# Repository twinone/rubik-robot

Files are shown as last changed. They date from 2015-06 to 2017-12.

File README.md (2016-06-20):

# rubik-robot

A low cost, 3D printable Rubik's Cube solving robot. This project was built in about two or three weeks, incuding the hardware design, software, etc. Just printing and assembling it should take about two days, so you can do it in a weekend. The total cost of the project is about 45$, from which 35$ are for the non-printable hardware, and 10$ are the actual printed parts.

Timelapse of the robot in action

## Hardware used

* 3D Printer (BQ Prusa i3 Hephestos)
* An Android phone (OnePlus One)
* 4x micro servo (TowerPro MG 995)
* 4x servo (Tower Pro SG 90)
* Arduino Nano, breadboard, jumper wires, etc.
* Bluetooth module (HC-05)
* M3 screws / nuts

## Parts

 - OpenSCAD designs for the printable parts (see `scad/`).
 - The sketch that runs on the Arduino (see `arduino/`).
 - An Android application (see `android/`) that uses the camera and works
   in cooperation with the Arduino to scan and solve the cube automatically.
 - Standalone utility apps (see `utils/`) for talking to the Arduino.

## Make your own

See [`BUILDING.md`](https://github.com/twinone/rubik-robot/blob/master/BUILDING.md)

## Authors

* [@twinone](https://github.com/twinone)
* [@jmendeth](https://github.com/jmendeth)

## License

Everything is MIT-licensed (see `LICENSE`) except this README and
the documentation files under `docs`, which are under a
[Creative Commons Attribution-NonCommercial 4.0 International License](https://creativecommons.org/licenses/by-nc/4.0).

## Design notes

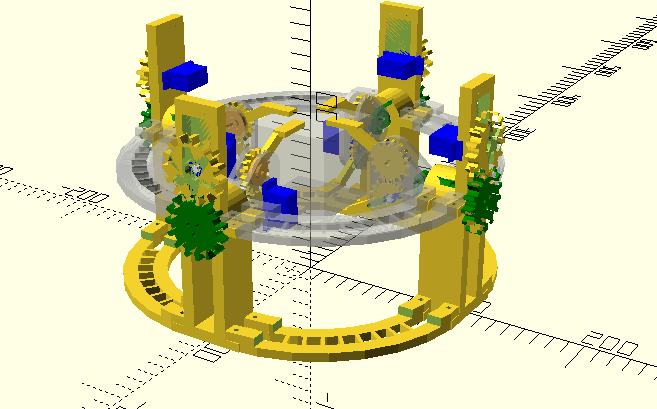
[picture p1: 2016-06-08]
docs/media/design.png

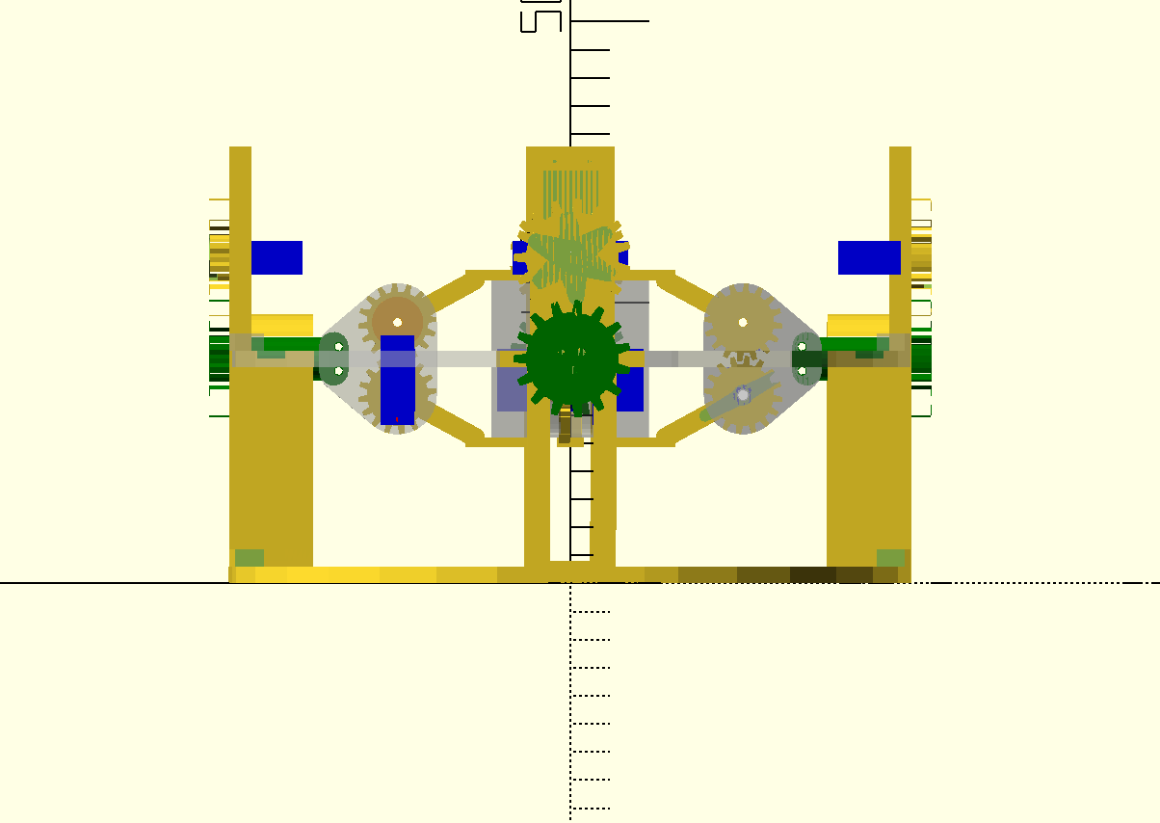
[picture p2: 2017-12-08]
docs/media/side.png

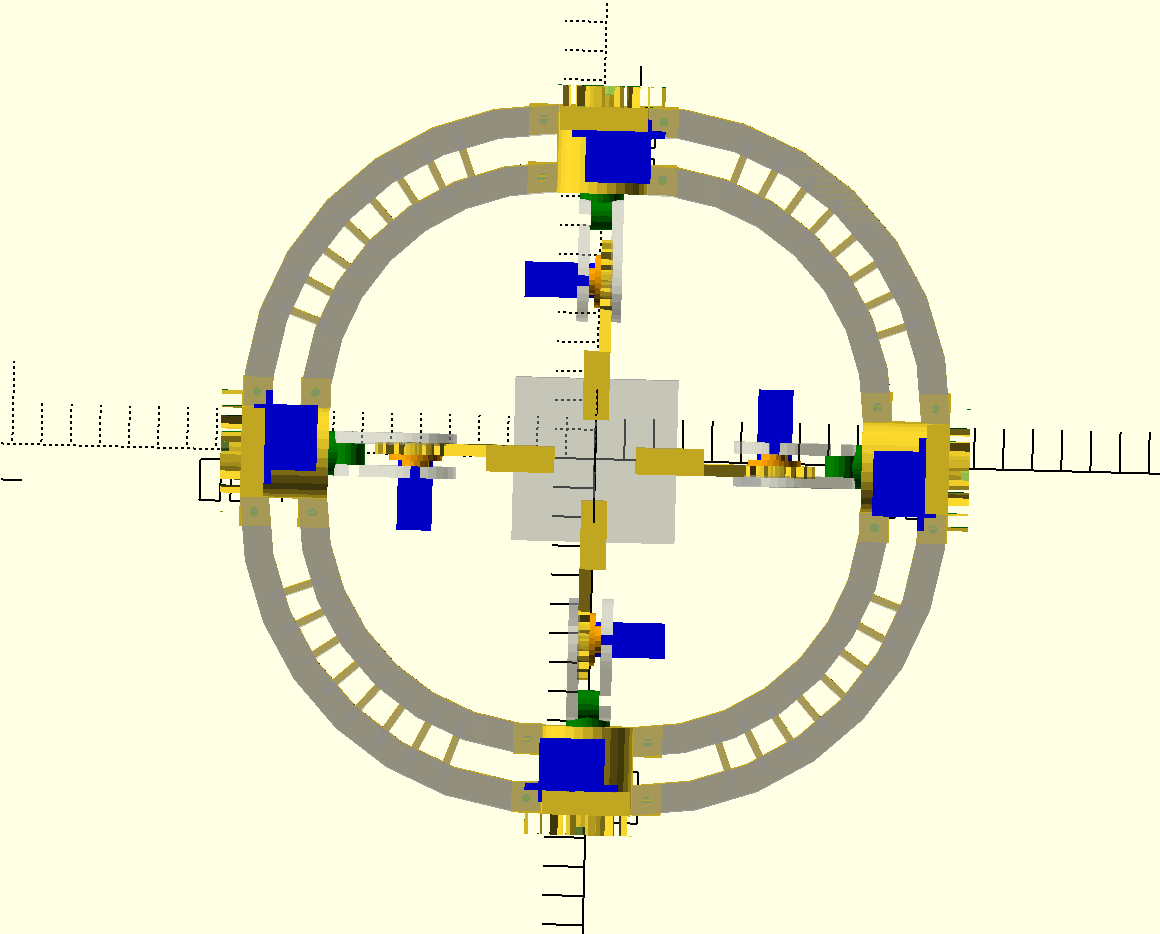
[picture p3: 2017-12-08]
docs/media/top.png

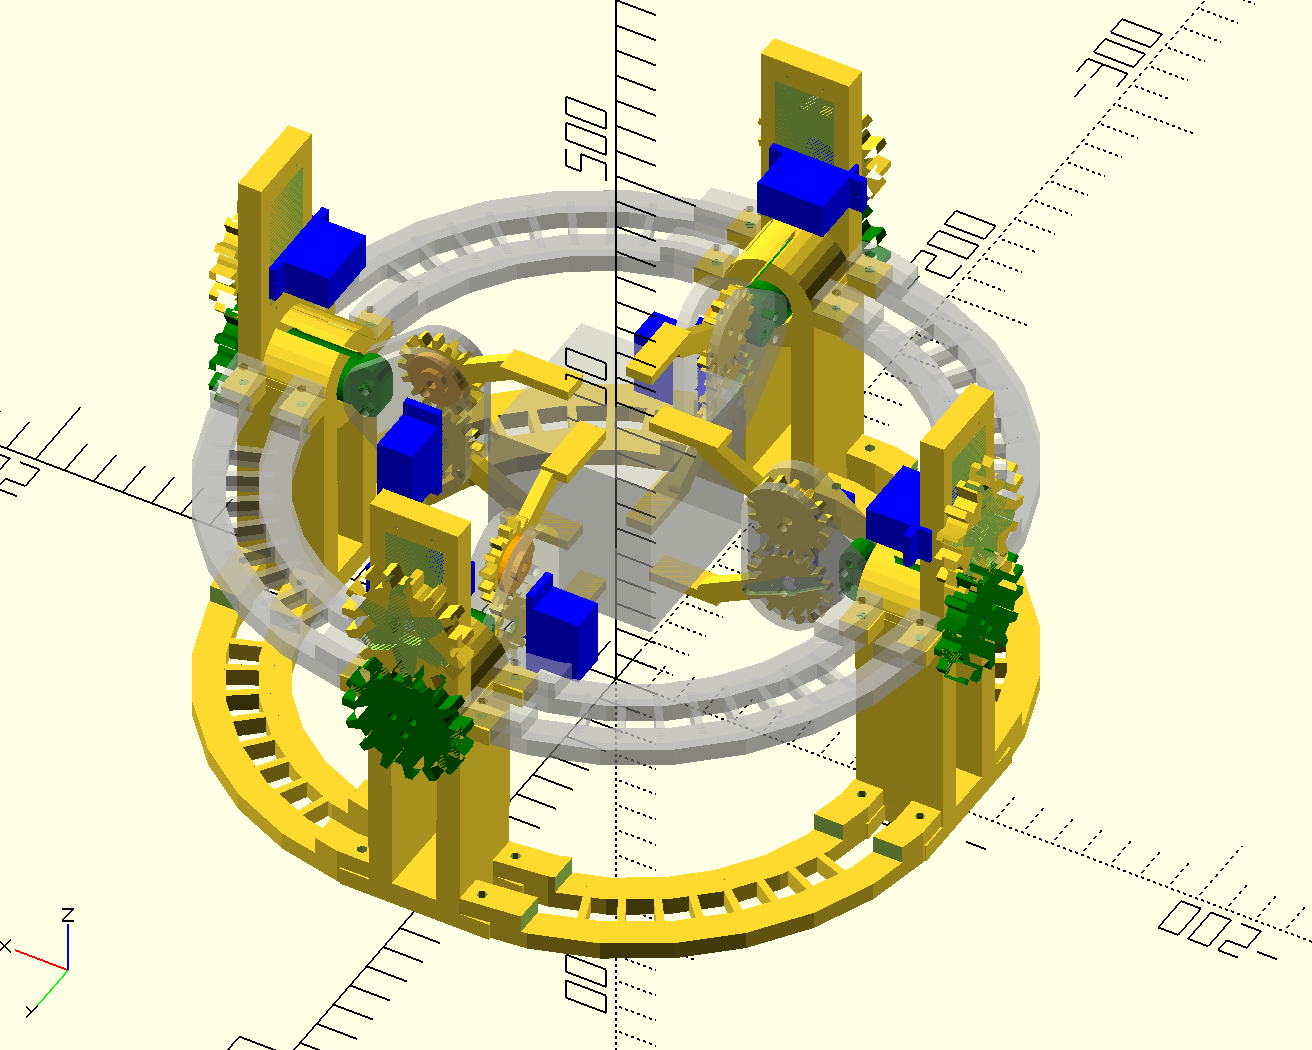
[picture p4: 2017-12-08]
docs/media/perspective.png

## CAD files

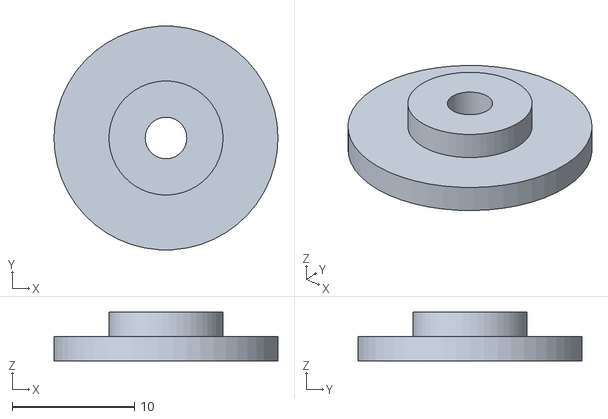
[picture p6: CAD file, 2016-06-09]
scad/build/grip_pad.stl
18.3 x 18.3 x 4.00

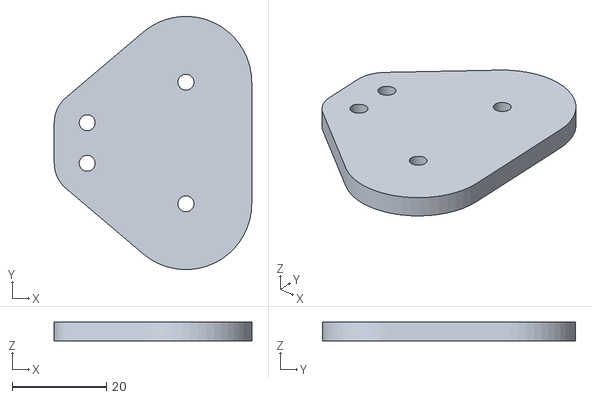
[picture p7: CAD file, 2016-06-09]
scad/build/grip_top.stl
42.0 x 53.8 x 4.00

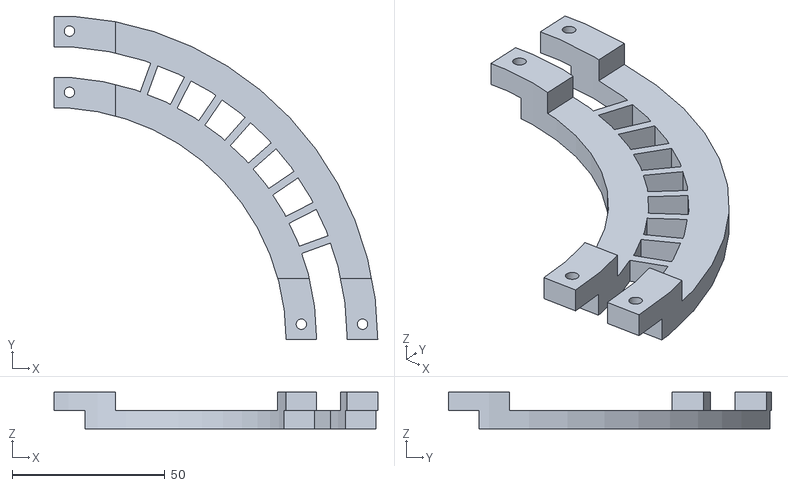
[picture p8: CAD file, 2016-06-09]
scad/build/foot.stl
105.8 x 105.6 x 12.0

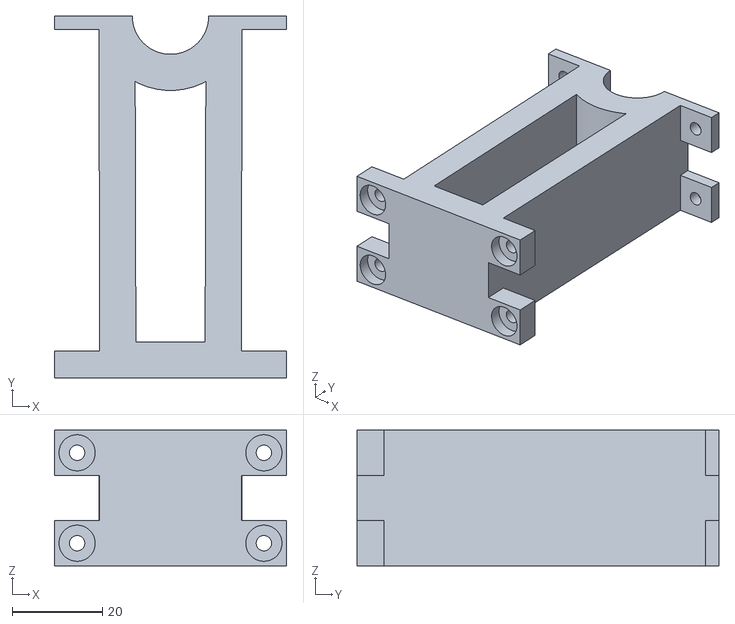
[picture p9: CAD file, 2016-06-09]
scad/build/holder_bottom.stl
51.3 x 80.0 x 30.0

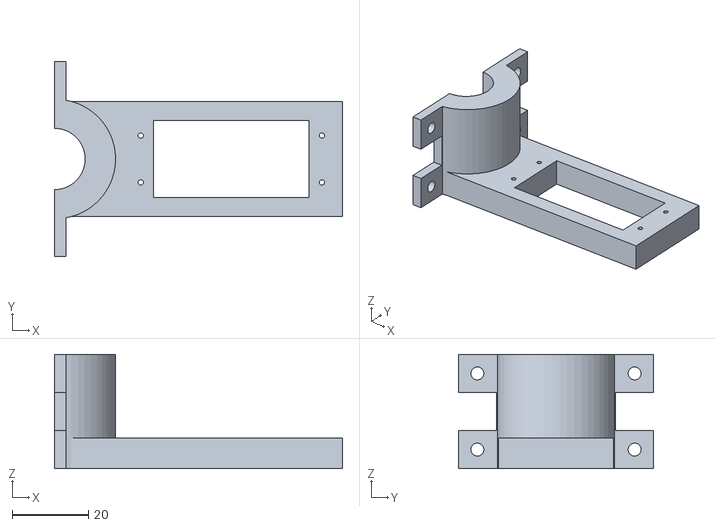
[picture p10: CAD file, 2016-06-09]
scad/build/holder_top.stl
75.7 x 51.3 x 30.0

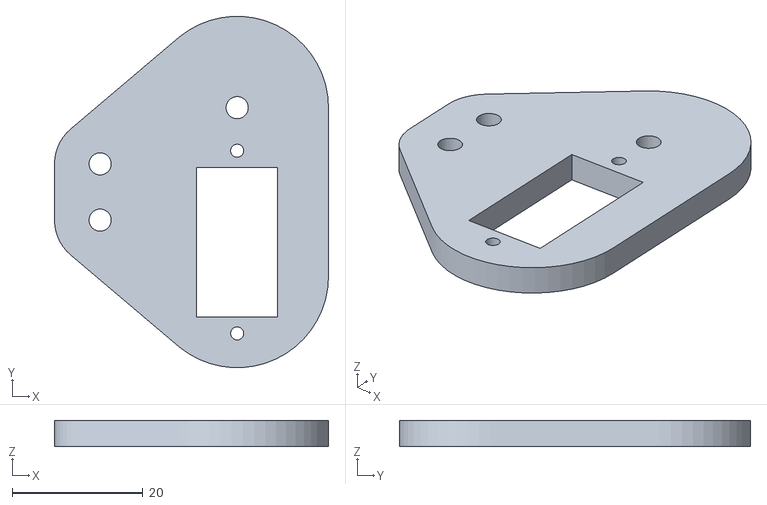
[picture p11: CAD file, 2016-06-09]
scad/build/grip_bottom.stl
42.0 x 53.8 x 4.00

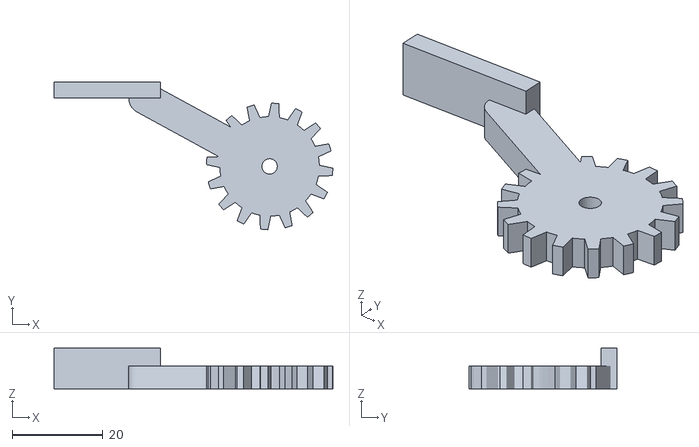
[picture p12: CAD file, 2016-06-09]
scad/build/arm_left.stl
61.6 x 32.6 x 9.00

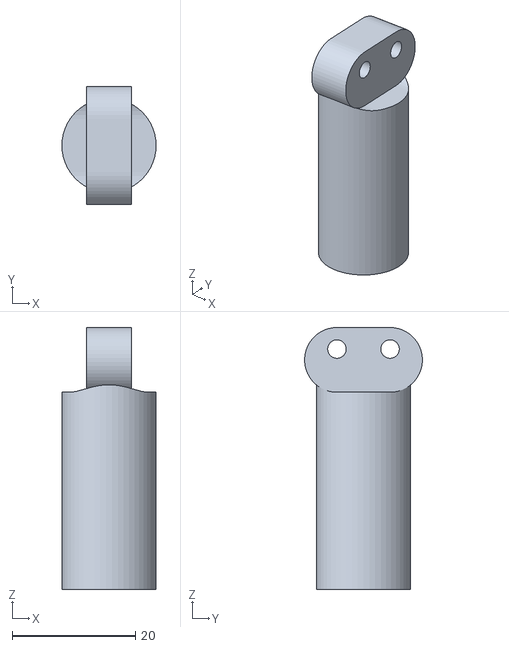
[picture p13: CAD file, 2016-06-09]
scad/build/grip_cylinder.stl
15.3 x 19.1 x 42.5

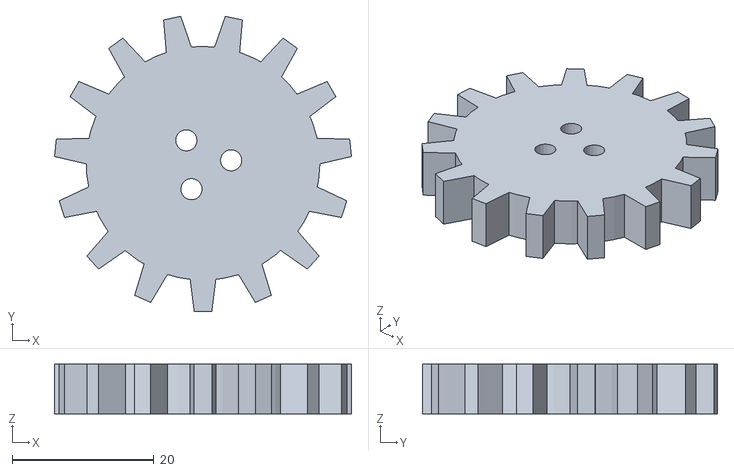
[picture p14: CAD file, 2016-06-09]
scad/build/grip_gear.stl
41.9 x 41.7 x 7.00

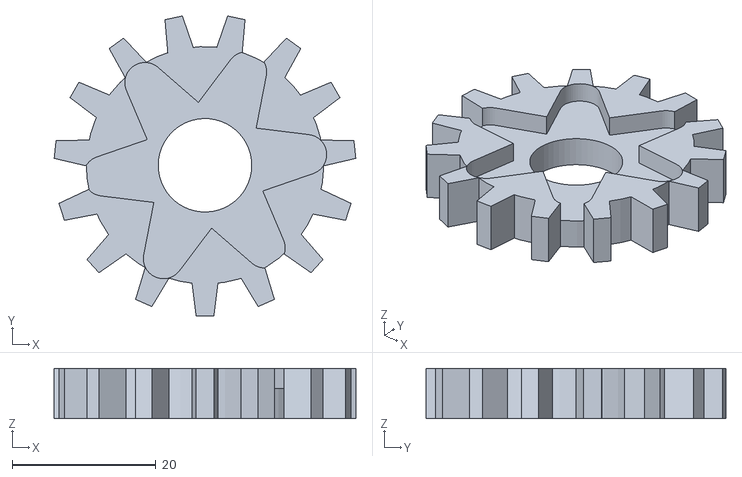
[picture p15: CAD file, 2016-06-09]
scad/build/servo_gear.stl
41.9 x 41.7 x 7.00

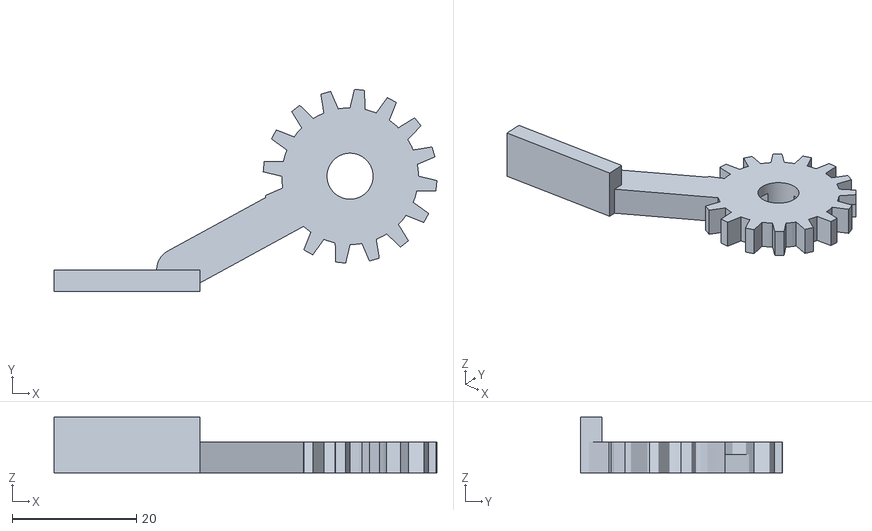
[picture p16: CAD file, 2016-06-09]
scad/build/arm_right.stl
61.6 x 32.6 x 9.00

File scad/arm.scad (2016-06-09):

use <buildvars.scad>
use <util/util.scad>
use <util/gear.scad>
use <util/mservo_enclosing.scad>

teeth = 16;
r = gear_r();


sideways_length = (56 - arm_c2c())/2;
// redefined here
function arm_length() = enclosing_dst_large() + 6;
l1 = arm_length();
l2 = sideways_length;
function arm_angle() = atan(l2/l1);
function arm_diagonal_length() = sqrt(l1*l1+l2*l2);

// length: center to center length
module arm(length, r=arm_width()/2, center = false, s1=true, s2=true) {
    move = center ? -length/2 : 0;
    translate([move,0,0])
    difference() {
        hull() {
            circle(r=r);
            translate([length,0,0])
            circle(r=r);
        }
        if(s1==true)
        screw_hole();
        if(s2==true)
        translate([length,0,0]) screw_hole();
    }
}
start_angle = 40;
angle = 360;

module sideways(height) {
    grip_h = 9;
    rotate(-90)
    translate([0,arm_length(),0]) {
        translate([0,0,height-grip_h])
        linear_extrude(height=grip_h)
        translate([sideways_length,-arm_width()/2,0]) square([arm_width()/2,20+arm_width()/2]);
    }
}

module arm_left(height) {
    mirror([0,1,0]) {
        gear(r=r, h=height, teeth=teeth, center_r = screw_r()+tolerance(), angle = angle, start_angle = start_angle);
        rotate(-arm_angle())
        linear_extrude(height=height) {
            arm(length=arm_diagonal_length(), r = arm_width()/2,s2=false);
        }
        sideways(height);
    }
}

module arm_right(height) {
    rotate(180-arm_angle())
    remove_servo_horn(horns=[true,false,true,false], h1=2)
    rotate(180+arm_angle())
    difference() {
        union() {
            rotate([0,0,-360/teeth/2]) // so they're aligned
            gear(r=r, h=height, teeth=teeth, center_r = screw_r()+tolerance(), angle = angle, start_angle = start_angle);
            rotate(-arm_angle())
            linear_extrude(height=height) {
                arm(length=arm_diagonal_length(), r = arm_width()/2,s2=false);
            }
            sideways(height);
        }
    }
}


module arms(height = arm_height(), center = true, angle = 0, extrasep = 0, left=true, right=true) {
    move = center ? -arm_c2c()/2 : 0;
    translate([0,move-extrasep,0]) {
        if(left)
        translate([0,arm_c2c()+extrasep*2,0])
        rotate([0,0,angle])
        arm_left(height);
        
        if(right)
        rotate([0,0,-angle])
        arm_right(height);
    }
}

arms();

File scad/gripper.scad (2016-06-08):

use <buildvars.scad>
use <arm.scad>

use <util/util.scad>
use <util/gear.scad>
use <util/mservo.scad>
use <util/mservo_enclosing.scad>


module dup(vec=[0,1,0]) {
    children();
    mirror(vec) children();
}


module base(servo_hole = true) {
    module main() {
        r = base_rounding_radius();
        module circles(r,a) {
            translate([0,arm_c2c()/2,0])
            circle(r=a?r:r*2);

            translate([back_y(),back_x()/2,0])
            circle(r=r);
        }
        linear_extrude(height=servo_base_height())
        difference() {
            hull() dup() circles(r,false);
            dup() circles(screw_r()+tolerance(),true, $fn=30);
            
        }
    }
    difference() {
        main();
        if (servo_hole) {
            translate([-servo_d()/2-tolerance(),-arm_c2c()/2+servo_w()-servo_r()+tolerance(),0]){
                rotate([0,0,-90]) {
                    cube([servo_w()+2*tolerance(),servo_d()+2*tolerance(),servo_base_height()]);
                }
            }
            translate([0,-arm_c2c()/2,0]){
                rotate([0,0,-90]) {
                    servo_screws();
                }
            }
        }
    }
}

module top() {
    base(false);
}

module show_servo() {
    translate([0,-arm_c2c()/2,0]){
        translate([0,0,-servo_base_height()*1])
        rotate([0,0,-90]) {
            translate([0,0,servo_base_height()]) servo();
        }
    }
}

module inset_arms(angle = 0) {
    linear_extrude(height=servo_base_height())
    dup() {
        translate([arm_inset_y(),arm_c2c()/2-arm_inset_x(),0])
        rotate([0,0,angle])
        arm(length=arm_length());
    }
}

module grippers(angle=0) {
    x = arm_inset_x();
    y = arm_inset_y();
    l = sqrt(x*x + y*y);
    translate([0,0,servo_base_height()])
    linear_extrude(height=servo_elevation()+servo_base_height()*0)
    dup() {
        translate([-arm_length()+cos(angle)*arm_length(),sin(angle)*arm_length(),0])
        translate([arm_length()+y,arm_c2c()/2-x,0]) {
            rotate(-atan(x/y)+180)
            arm(length=l);
            arm(length=l/2);
        }
    }
}


module pusher() {
    linear_extrude(height=servo_elevation())
    arm();
}
module pusher_big() {
    translate([0,0,2])
    linear_extrude(2)
    arm(r=gear_r()/1.2);
    linear_extrude(height=2)
    arm(r=arm_width()/1.5);    
}

module turner() {
    
    sr = turn_sr();
    br = turn_br();
    mr = turn_mr();
    h = back_h();
    
    turner_height = 10;
    module s(h) {
        linear_extrude(height=h)
        difference() {
            hull()
            dup()
            translate([-(br+sr)/2+sr,back_x()/2,0])
            circle(r=mr);

            dup()
            translate([0, back_x()/2,0])
            circle(r=screw_r()); // without tolerance for better grip
        }
    }
    translate([0,0,servo_base_height()])
    s(h-servo_base_height()*2);
    
    gap_h = turn_gap_h();
    gap_d = turn_gap_d();
    pad = turn_pad();
    sd = 10;
    difference() {
        translate([-br+sr-pad,0,h/2])
        rotate([0,-90,0]) {
            difference() {
                cylinder(r=h/2, h=turn_h()+sr);
                
                translate([0,0,turn_h()+sr-sd])
                turner_screws(h=sd);
            }
        }
        
        s(h);
    }
}

module turner_screws(h, r=screw_r()) {
    $fn=20;
    sdst = 4;
    n = 3;
    in = 10;
    for (i = [0:n-1])
    rotate(360/n*i)
    translate([sdst,0,-in])
    cylinder(r=r,h=60);
}

module display_turner() {
    translate([turn_br()+turn_pad(),0,-gripper_r()]) turner();
}



module display_gripper() {
    tgt = 90;
    arm_angle = $t < 0.5 ? $t*2*tgt : tgt-($t-0.5)*2*tgt;
    
    // BASE
    //color("red")
    %translate([0,0,servo_base_height()]) {
        base();
        show_servo();
    }
    
    %translate([0,0,servo_elevation()+servo_base_height()*2+nut_h()])
    top();


    // GEAR ARMS
    translate([0,0,servo_elevation()*0+servo_base_height()*3])
    arms(height = servo_base_height(), center = true, angle=arm_angle);
  

    // PUSHERS
    translate([0,0,servo_base_height()])
    color("orange") {
        translate([0,arm_c2c()/2,servo_base_height()*1])
        pusher_big();
    }
    
    color("green")
    translate([back_y(),0,servo_base_height()])
    turner();
}

display_gripper();

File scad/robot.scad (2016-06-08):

use <scad-utils/morphology.scad>

use <buildvars.scad>
use <gripper.scad>
use <arm.scad>
use <holder.scad>
use <foot.scad>
use <gears.scad>

use <util/gear.scad>
use <util/servo_enclosing.scad>
use <util/mservo_enclosing.scad>
use <util/mservo.scad>
    

tgt = 90;
angle = $t < 0.5 ? $t*2*tgt : tgt-($t-0.5)*2*tgt;
angle=-25+180;

module display() {
    translate([0,holder_w()/2,holder_h()])
    mirror()
    
    rotate([90,0,0])
    translate([back_y(),0,servo_base_height()]*-1)
    translate([turn_br()+turn_pad(),0,-gripper_r()])
    display_gripper();

    translate([holder_d(),holder_w()/2,holder_h()+gears_c2c()]) {
        servo_gear();
        translate([-servo_elevation()-servo_base_height()*1+1,0,0])
        rotate([-90,180,-90]) {
            servo();
        }
    }

    rotate([90,0,90])
    holder_bottom();
    holder_top();
    
    color("green")
    translate([holder_d(), holder_w()/2, holder_h()])
    rotate([0,90,0])
    turner_gear();
}


module display4() {
    for (i = [0:3]) {
        rotate(i*90) {
            translate([holder_dst()/2,-holder_w()/2,0])
            display();
            foot();
            translate([0,0,holder_h()-sh_h()])
            %foot();
        }
    }
    
    %translate([0,0,holder_h()])
    cube([1,1,1]*56,center=true);
}


display4();

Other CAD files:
scad/servo_horn_enclosing.scad
scad/base.scad
scad/buildvars.scad
scad/export.scad
scad/foot.scad
scad/gears.scad
scad/gripper/arm.scad
scad/gripper/buildvars.scad
scad/gripper/gripper.scad
scad/gripper/micro_servo.scad
scad/gripper/micro_servo_horn_enclosing.scad
scad/gripper/util.scad
scad/gripper_v2/base.scad
scad/holder.scad
scad/phone_holder.scad
scad/scad-utils/hull.scad
scad/scad-utils/linalg.scad
scad/scad-utils/mirror.scad
scad/scad-utils/morphology.scad
scad/scad-utils/se3.scad
scad/scad-utils/so3.scad
scad/scad-utils/spline.scad
scad/scad-utils/trajectory.scad
scad/scad-utils/trajectory_path.scad
scad/scad-utils/transformations.scad
scad/util/gear.scad
scad/util/mservo.scad
scad/util/mservo_enclosing.scad
scad/util/screw.scad
scad/util/servo.scad
scad/util/servo_enclosing.scad
scad/util/util.scad

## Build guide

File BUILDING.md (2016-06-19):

# Building
This file contains the steps needed to build the robot

# The parts

* 3D print the following parts

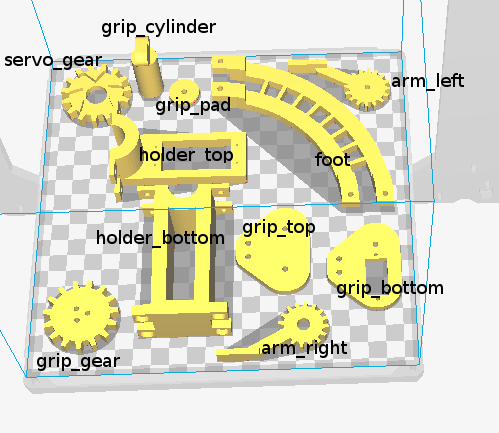
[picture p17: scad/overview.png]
overview


Amount | Piece | 1 Piece time | Total time | Support
--- | --- | --- | --- | ---
4x | [arm_left](https://github.com/twinone/rubik-robot/blob/master/scad/build/arm_left.stl) | 00:25 | 01:40 | no
4x | [arm_right](https://github.com/twinone/rubik-robot/blob/master/scad/build/arm_right.stl) | 00:25 | 01:40 | **yes**
4x | [grip_top](https://github.com/twinone/rubik-robot/blob/master/scad/build/grip_top.stl) | 00:40 | 02:40 | no
4x | [grip_bottom](https://github.com/twinone/rubik-robot/blob/master/scad/build/grip_bottom.stl) | 00:35 | 02:20 | no
4x | [grip_pad](https://github.com/twinone/rubik-robot/blob/master/scad/build/grip_pad.stl) | 00:05 | 00:20 | no
4x | [grip_cylinder](https://github.com/twinone/rubik-robot/blob/master/scad/build/grip_cylinder.stl) | 00:45 | 03:00 | no
4x | [holder_top](https://github.com/twinone/rubik-robot/blob/master/scad/build/holder_top.stl) | 00:45 | 03:00 | **yes**
4x | [holder_bottom](https://github.com/twinone/rubik-robot/blob/master/scad/build/holder_bottom.stl) | 01:30 | 06:00 | **yes**
4x | [servo_gear](https://github.com/twinone/rubik-robot/blob/master/scad/build/servo_gear.stl) | 00:20 | 01:20 | no
4x | [grip_gear](https://github.com/twinone/rubik-robot/blob/master/scad/build/grip_gear.stl) | 00:20 | 01:20 | no
8x | [foot](https://github.com/twinone/rubik-robot/blob/master/scad/build/foot.stl) | 01:00 | 08:00 | **yes**

Total printing time: 27h (measured for a BQ Prusa i3 Hephestos at medium quality)

You can print them all using a 15-20% infill and walls of 1mm. Layer height of up to 0.3mm is fine. It's recommended to print parts one by one, especially the bigger ones, so you don't have to start again more than one piece when one of them fails.

* Non-printable hardware

Amount | Type | Unit price | Total price
--- | --- | --- | ---
4x | [Tower Pro MG90S micro servo](http://www.aliexpress.com/item/New-MG90S-Gear-Metal-Servo-Micro-Servo-For-Boat-Car-Plane-Helicopter/32627521737.html) | $2.74 | $10.96
4x | [Tower Pro MG995 servo](http://www.aliexpress.com/item/Towerpro-Servos-Digital-MG995-Servo-Metal-Gear-for-Arduino-Board-DIY-Smart-Vehicle-Helicopter-Airplane-Aeroplane/32465724289.html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,searchweb201602_1_10037_10017_507_10032_401,searchweb201603_6&btsid=a9de8b50-e2ea-4e2f-8265-d85bdd6a58ad) | $3.86 | $15.44
1x | [Arduino Nano V3.0](http://www.aliexpress.com/item/Nano-CH340-ATmega328P-MicroUSB-Compatible-for-Arduino-Nano-V3/32572612009.html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,searchweb201602_1_10037_10017_507_10032_401,searchweb201603_6&btsid=996c5237-8b2a-4063-bbd8-3e84b59453f0) | $1.88 | $1.88
1x | [HC-06 Bluetooth Module](http://www.aliexpress.com/item/Free-shipping-HC06-HC-06-Wireless-Serial-4-Pin-Bluetooth-RF-Transceiver-Module-RS232-TTL-for/32446248487.html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,searchweb201602_1_10037_10017_507_10032_401,searchweb201603_6&btsid=b3f8c97e-f215-4245-b35a-6c0416e155e0) | $2.75 | $2.75
1x | [Breadboard](http://www.aliexpress.com/item/1pcs-Quality-mini-bread-board-breadboard-8-5CM-x-5-5CM-400-holes-For-expansion-arduino/1906352269.html) | $1.07 | $1.07
1x | [Jumper wires](http://www.aliexpress.com/item/120pcs-20cm-male-male-male-female-and-female-jumper-wire-Dupont-cable-for-Arduino/1728903423.html) | $2.65 | $2.65

Total price: $34.75 (€30.68)

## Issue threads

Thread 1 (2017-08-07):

Servo designation and orientation

ghendley, 2017-08-07:
Which servo in the servo list corresponds to each physical servo? How does one orient the servos when first setting up the robot (what degree 0-180 corresponds to what position for each type of servo)?

I have printed the parts and begun assembly, but I am not sure how to configure the servos and am therefore stuck at the moment.

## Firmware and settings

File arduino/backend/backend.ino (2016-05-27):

#include <Servo.h>

// MOTOR PARAMS

int servo_pins [8] = {
  5,6,7,8,9,10,11,12
};

// PROTOCOL

#define REQUEST_NOOP 0x00
#define REQUEST_RESUME 0x01
#define REQUEST_DELAY 0x02
#define REQUEST_BUFFER 0x03

#define REQUEST_CALIBRATE 0x10
#define REQUEST_DETACH 0x11
#define REQUEST_WRITE 0x12

#define RESPONSE_OK 0x00
#define RESPONSE_INVALID_COMMAND 0x01
#define RESPONSE_INVALID_ARGUMENT 0x02

// CODE

Servo servos [8];
boolean servos_attached [8];

boolean processingRequests = true;

void setup() {
  pinMode(13, OUTPUT); //FIXME
  Serial.begin(9600);// 115200);
}

void processRequest() {
  int length = Serial.read();
  if (length == -1) return;
  char data [length];
  while (Serial.available() < length);
  if (Serial.readBytes(data, length) < length || length < 1) return;
  
  char id = data[0];
  if (!processingRequests && id != REQUEST_RESUME) return;
  switch (id) {
    case REQUEST_NOOP:
      requestNoop(data, length);
      break;
    case REQUEST_RESUME:
      requestResume(data, length);
      break;
    case REQUEST_DELAY:
      requestDelay(data, length);
      break;
    case REQUEST_BUFFER:
      requestBuffer(data, length);
      break;
    case REQUEST_DETACH:
      requestDetach(data, length);
      break;
    case REQUEST_WRITE:
      requestWrite(data, length);
      break;
    default:
      emitResponseSimple(RESPONSE_INVALID_COMMAND);
      processingRequests = false;
  }
}

void emitResponse(char *data, int length) {
  Serial.write(length);
  Serial.write((unsigned char*)data, length);
}

void emitResponseSimple(char id) {
  char data [1] = { id };
  emitResponse(data, 1);
}

void requestNoop(char *data, int length) {
  if (length != 1) {
    emitResponseSimple(RESPONSE_INVALID_ARGUMENT);
    processingRequests = false;
    return;
  }
  emitResponseSimple(RESPONSE_OK);
}

void requestResume(char *data, int length) {
  if (length != 1) {
    emitResponseSimple(RESPONSE_INVALID_ARGUMENT);
    processingRequests = false;
    return;
  }
  processingRequests = true;
  emitResponseSimple(RESPONSE_OK);
}

void requestDelay(char *data, int length) {
  if (length != 3) {
    emitResponseSimple(RESPONSE_INVALID_ARGUMENT);
    processingRequests = false;
    return;
  }
  int time = ((unsigned char*)data)[1] << 8;
  time |= ((unsigned char*)data)[2];
  delay(time);
  emitResponseSimple(RESPONSE_OK);
}

void requestBuffer(char *data, int length) {
  if (length != 2) {
    emitResponseSimple(RESPONSE_INVALID_ARGUMENT);
    processingRequests = false;
    return;
  }
  unsigned char peek = ((unsigned char *)data)[0];
  while (Serial.available() < peek);
  emitResponseSimple(RESPONSE_OK);
}

void requestDetach(char *data, int length) {
  if (length != 2) {
    emitResponseSimple(RESPONSE_INVALID_ARGUMENT);
    processingRequests = false;
    return;
  }
  int motor = data[1];
  if (motor < 0 || motor >= 8) {
    emitResponseSimple(RESPONSE_INVALID_ARGUMENT);
    processingRequests = false;
    return;
  }
  if (servos_attached[motor]) {
    servos[motor].detach();
    servos_attached[motor] = false;
  }
  emitResponseSimple(RESPONSE_OK);
}

void requestWrite(char *data, int length) {
  if (length != 3) {
    emitResponseSimple(RESPONSE_INVALID_ARGUMENT);
    processingRequests = false;
    return;
  }
  int motor = data[1], pos = ((unsigned char *)data)[2];
  if (motor < 0 || motor >= 8 || pos < 0 || pos > 180) {
    emitResponseSimple(RESPONSE_INVALID_ARGUMENT);
    processingRequests = false;
    return;
  }
  if (!servos_attached[motor]) {
    servos[motor].attach(servo_pins[motor]);
    servos_attached[motor] = true;
  }
  servos[motor].write(pos);
  emitResponseSimple(RESPONSE_OK);
}

void loop() {
  while (true) processRequest();
}

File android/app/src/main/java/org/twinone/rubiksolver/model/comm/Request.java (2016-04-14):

package org.twinone.rubiksolver.model.comm;

/**
 * Represents a request made to the backend.
 */
public abstract class Request {

    public static final byte REQUEST_NOOP = 0x00;
    public static final byte REQUEST_RESUME = 0x01;
    public static final byte REQUEST_DELAY = 0x02;
    public static final byte REQUEST_BUFFER = 0x03;

    public static final byte REQUEST_CALIBRATE = 0x10;
    public static final byte REQUEST_DETACH = 0x11;
    public static final byte REQUEST_WRITE = 0x12;

    public abstract byte getId();

    public abstract byte[] encode();
    
    
    public static final int SIDE_RIGHT = 0;
    public static final int SIDE_UP = 1;
    public static final int SIDE_LEFT = 2;
    public static final int SIDE_DOWN = 3;

    public static final int MOTOR_GRIP = 0;
    public static final int MOTOR_ROTATION = 1;
    
    public static int getMotor(int side, int motor) {
        if (side < 0 || side >= 4) throw new IllegalArgumentException("Invalid side specified");
        if (motor < 0 || motor >= 2) throw new IllegalArgumentException("Invalid motor specified");
        return (side << 1) | motor;
    }

}

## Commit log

2015-06-20 Prepared base to work with
    [base.scad]
2015-06-22 Base updated
    [base.scad]
2015-07-13 Add servo support
    [servo_support.scad]
2015-07-13 Added arduino sample code
2016-03-29 Add servo horn enclosing
    [servo_horn_enclosing.scad]
2016-03-29 Finish gripper design
    [arm.scad, base.scad, buildvars.scad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]
2016-03-31 Make gripper a bit smaller, for more force
    [arm.scad, base.scad, buildvars.scad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]
2016-04-06 Update gripper, add gripper turner
    [arm.scad, base.scad, buildvars.scad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]
2016-04-06 Finish prototype of gripper holder after a long day
    [base.scad, buildvars.scad, gear.scad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]
2016-04-07 Parse algorithm; translate to servo movements
2016-04-08 Make c2c and force factor modular, change gear attachments
    [base.scad, gripper.scad, servo.scad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]
2016-04-09 Update horn enclosing, allow gear to round, tune conversion factor to final value
    [base.scad, gear.scad, servo_horn_enclosing.scad]
2016-04-09 Add arm.mp4
2016-04-10 Add cable holder
    [arm.scad, base.scad, gear.scad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]
2016-04-10 Make gripper thinner (and more stable), show full robot in base.scad
    [arm.scad, base.scad, gripper.scad]
2016-04-11 Show cube
    [base.scad]
2016-04-11 Fixes in backend sketch
    [backend.ino]
2016-04-12 Little bigger horn hole
    [arm.scad, gripper.scad]
2016-04-14 Fixes in model & mapper
    [SimpleRobotMapper.java]
2016-04-14 model: Move side/motor mapping to general class
2016-04-14 Add DetachRequest, servos now start detached until moved
2016-04-14 Remove move request & calibration from arduino
    Calibration will now happen entirely in the client.
2016-04-14 Implement calibration + overshoot corrections on mapper
    [SimpleRobotMapper.java]
2016-04-14 SimpleController: Improvements & fixes
    - Added detach buttons
    - Used mapper for all moves now
    - Resolve bug when setting gripper to 180
    - Info is printed on the console as requests complete
    - Set send ahead buffer to 1
    - Send probe to test robot is listening, before showing UI
    [GripPanel.java, RotationPanel.java, SimpleController.java]
2016-05-18 Refactor into v1.0
    [arm.scad, base.scad, buildvars.scad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]
2016-05-18 Add scad-utils library
    [hull.scad, linalg.scad, mirror.scad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]
2016-05-18 Create v1.1 based on v1.0
    [arm.scad, base.scad, buildvars.scad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]
2016-05-20 Remove v1.0 in favour of tags
    [arm.scad, base.scad, buildvars.scad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]
2016-05-20 Add prepare work for bigger servos
    [base.scad, micro_servo.scad, micro_servo_horn_enclosing.scad]
2016-05-22 Add servo_adapter for bigger servo
    [base.scad]
2016-05-23 Created new top for big servos
    [base.scad, big_servo_enclosing.scad, gripper.scad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]
2016-05-27 robot: Fixes; revert some hacks
    [SimpleController.java, SimpleRobotMapper.java]
2016-05-28 Make Arduino great again
2016-05-29 controller: Remove resend button
2016-05-29 controller: UI misc fixes
    [SimpleController.java]
2016-05-29 arduino: Revert changes up to 5f73d0a1
    SoftwareSerial often lost bytes.
    [backend.ino]
2016-05-30 Fixes in advanced mapper and controller
    [SimpleController.java]
2016-06-02 app: Remove current web
2016-06-02 Push calibration
2016-06-03 Don't track eclipse files
2016-06-04 Revert "refactor offsets to be public static"
    This reverts commit b2417f09ce3e4804f01e4251b8b6d7681f354dc6.
    [SimpleRobotMapper.java]
2016-06-05 Release camera after capturing, add flash toggle
2016-06-05 Don't track maps
2016-06-08 Fix dependencies
    [arm.scad, base.scad, gripper.scad]
2016-06-08 rename base->robot
    [robot.scad]
2016-06-08 Clenaup gripper.scad
    [gripper.scad]
2016-06-08 Rename everything out of gripper/
    [arm.scad, big_servo_enclosing.scad, buildvars.scad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]
2016-06-08 Fix small bug
    [arm.scad]
2016-06-08 Fix small bug (yes, really this time), remove commented lines
    [arm.scad]
2016-06-08 Cleanup & separate scad into files for each module
    [arm.scad, buildvars.scad, foot.scad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]
2016-06-08 app: Tighten face rotation delays
    [SimpleRobotMapper.java]
2016-06-08 app: Make buttons smaller, hide both when scanning
2016-06-09 Add build.sh
    [arm.scad, buildvars.scad, export.scad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]
2016-06-09 Added builds
    [arm_left.stl, arm_right.stl, foot.stl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]
2016-06-09 Add printing times
2016-06-09 Turn around grip_pad 180º for better printing
    [export.scad, grip_pad.stl]
2016-06-20 README: Note type of screw used
